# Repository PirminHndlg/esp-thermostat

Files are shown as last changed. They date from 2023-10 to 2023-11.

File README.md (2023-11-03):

# ESP-Thermostat

In Zeiten, in denen das Heizen ein Vermögen kostet, haben viele Haushalte sich entschieden, Smarte Thermostate zur Steuerung der Raumtemperatur zu kaufen. Diese kosten allerdings gerne 60-100 €, was ich für zu teuer halte und nicht bereit bin zu zahlen.

Deshalb habe ich mich dazu entschlossen, mein eigenes Thermostat zu bauen!

Das Ergebnis des Bauprozesses möchte ich hier veröffentlichen. Die Kosten für den Eigenbau sind ca. 10-15 €.

## Konzeptidee
Meine Idee ist, dass ich, wie bei gekauften smarten Thermostaten, das bestehende Thermostat ersetze. Allerdings nutze ich den Metall-Anschluss-Ring des originalen Thermostats zur Befestigung. Mit einem kleinen Schrittmotor und einem Wemos D1 Mini Mikrocontroller lässt sich der Bolzen der Heizung steuern, der beeinflusst, wie viel warmes Wasser in den Heizkörper fließt. Die Bewegung wird mit einer Schraube getätigt, die vom Motor gedreht wird und somit zur Heizung bzw von ihr weg bewegt wird.

YouTube-Video zum Bauprozess [hier](https://www.youtube.com/watch?v=YOUTUBE_VIDEO_ID_HERE) - Link fehlt noch

IMAGE ALT TEXT HERE (https://www.youtube.com/watch?v=YOUTUBE_VIDEO_ID_HERE)

### Vorteile
- OpenSource
- einfach umsetzbar
- Raumtemperatur über Zeitplan steuerbar
- billig
- 3D Drucker nicht zwingend notwenig

### Nachteile
- Thermostat braucht Stromversorgung über Kabel (Akku nicht gut möglich)
- Raumtemperatur nicht am Thermostat steuerbar sondern nur über Website / Einbindung in SmartHome-App

## Einstellungen auf lokaler Website
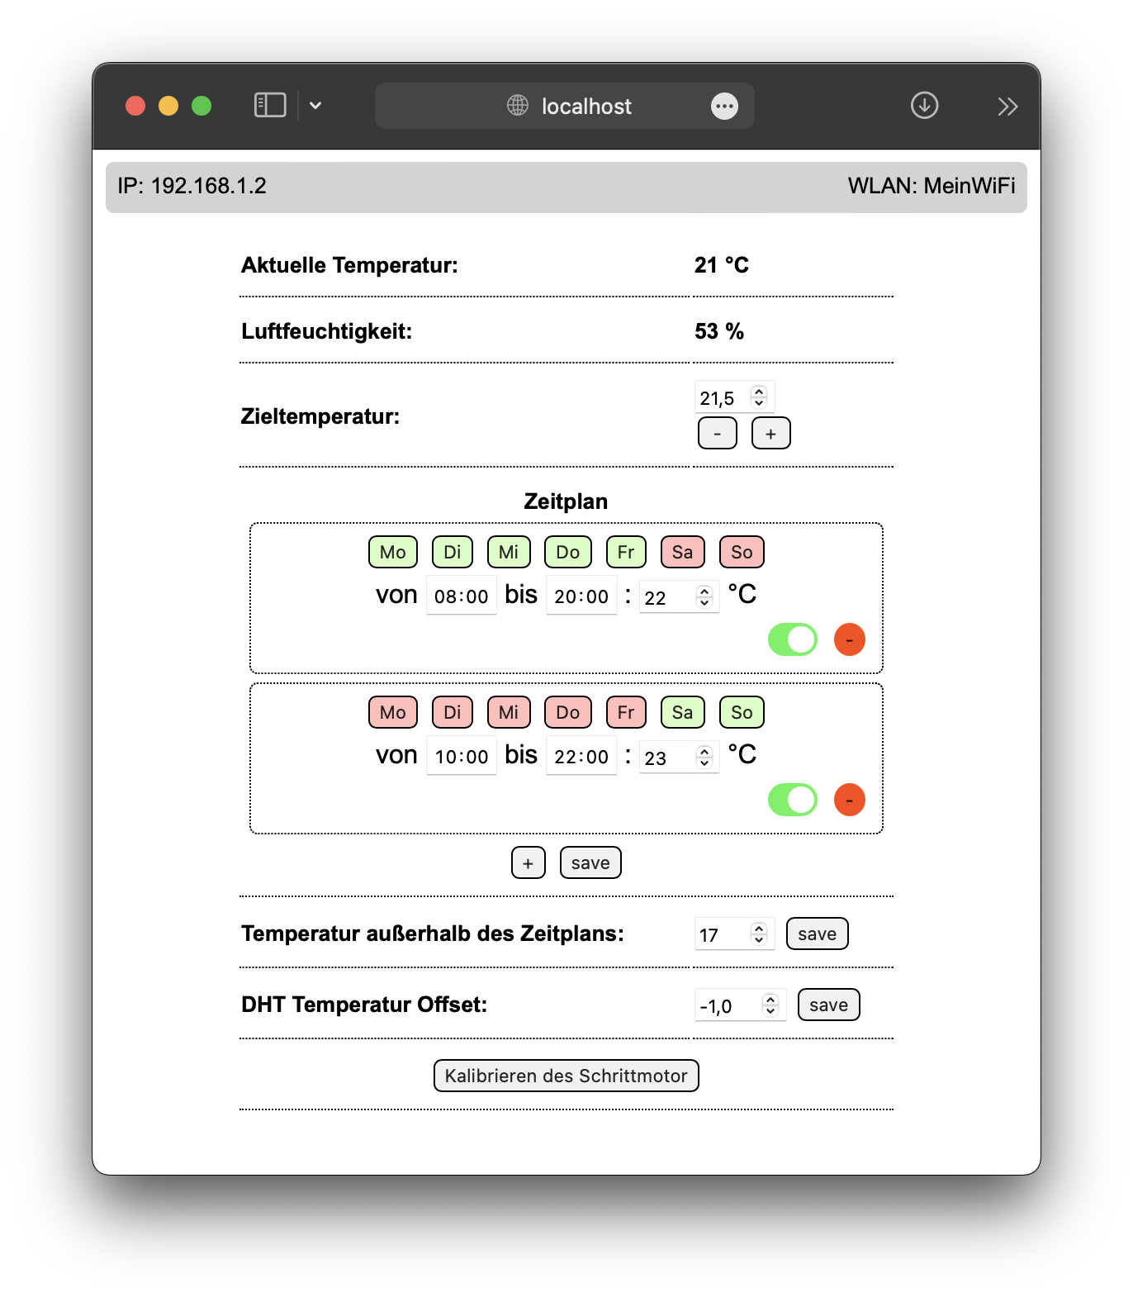
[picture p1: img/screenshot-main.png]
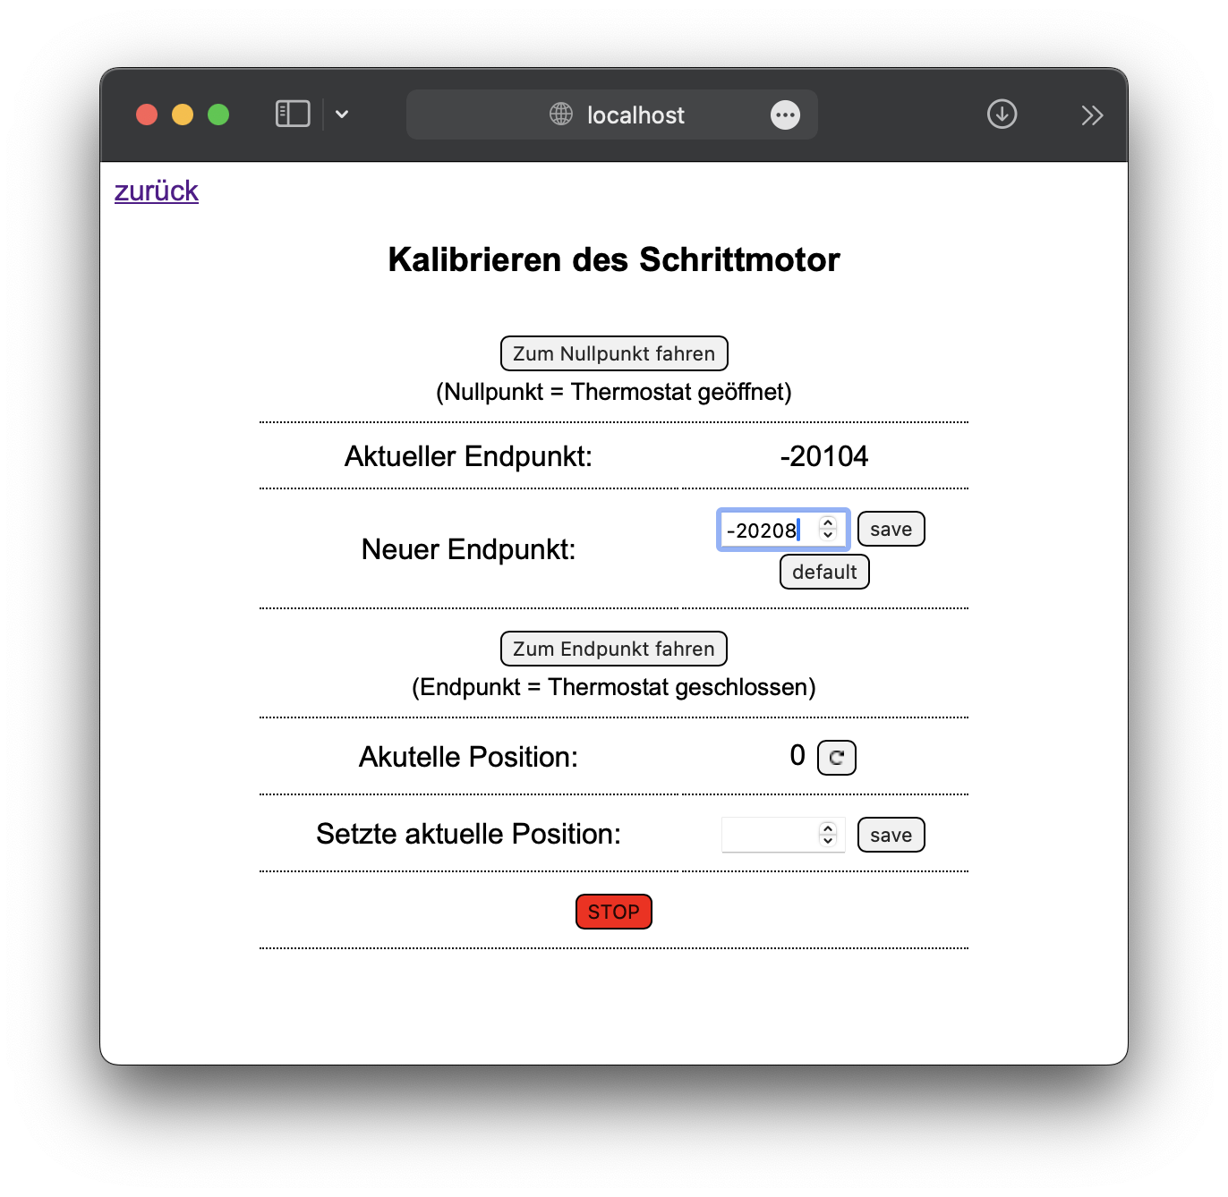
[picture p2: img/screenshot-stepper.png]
 
Der ESP erzeugt eine Website, über die sich Einstellungen für das Thermostat vornehmen lassen. Es ist möglich, einen Zeitplan zu erstellen oder die Zieltemperatur für den Raum einzustellen. Die Offsettemperatur des Temperatursensors ist dafür da, da es sein kann, dass die Temperatur direkt neben der Heizung höher ist als im restlichen Raum.

## Empfohlenes Vorwissen
- Löten
- Erfahrung mit Arduinos oder ESPs

## Benötigte Materialien
### Bauteileliste
- Wemos D1 Mini [^1]
- 28byj-48 Stepper Motor + Driver Modul (Standardmotor in Arduino Kits)
- DHT11 oder DHT22 (geht aber auch ohne)

[^1]: oder ähnlichen ESP8266, dann muss man das Case aber ggf. anpassen

### Werkzeuge
- Lötkolben
- Möglichst 3D Drucker (nicht zwingend notwendig, Kauf der Teile auch möglich)

### Kleinzeug
- 1x Female-Steckpins für D1 Mini
- Kabel zum Verlöten
- 3x M3 Schraube (25mm oder besser 30mm) + 3x M3 Mutter
- Micro USB Kabel + Netzteil

Natürlich benötigt man auch einen Laptop mit der [Arduino IDE](https://www.arduino.cc/en/software) zum Programmieren des ESPs

## 3D-Druck-Dateien
Da viele Leute keien 3D Drucker besitzen habe ich mich entschieden die gedruckten Teile selber auf [etsy](etsy.com) zu verkaufen. Dabei biete ich die Teile für den Filamentpreis an und habe kein Interesse daran große Gewinne zu machen.

Allerdings besitze ich nur einen Prusa Mini, somit ist die Qualität der Drucke nicht die beste.

Link zum Verkauf: [hier](etsy.com) - Link fehlt noch

## Richtiger Anschluss und Gewinde des Heizkörperventils ermitteln
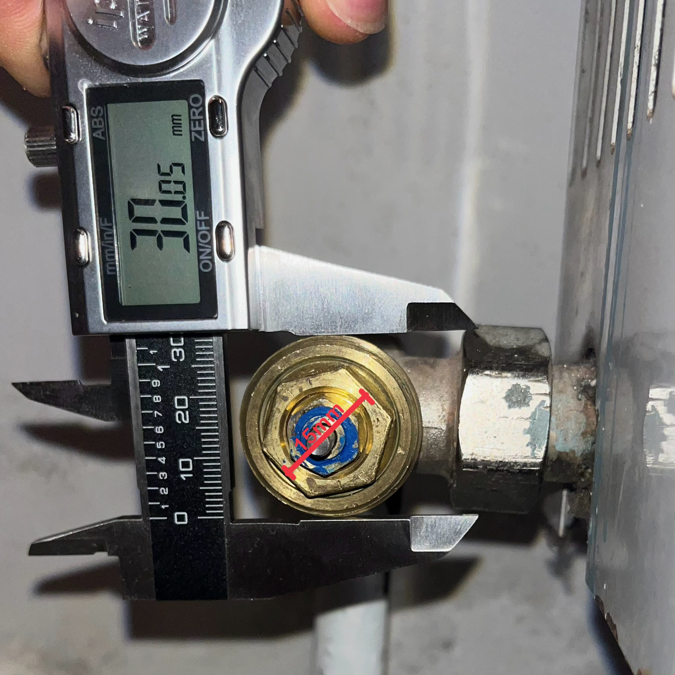
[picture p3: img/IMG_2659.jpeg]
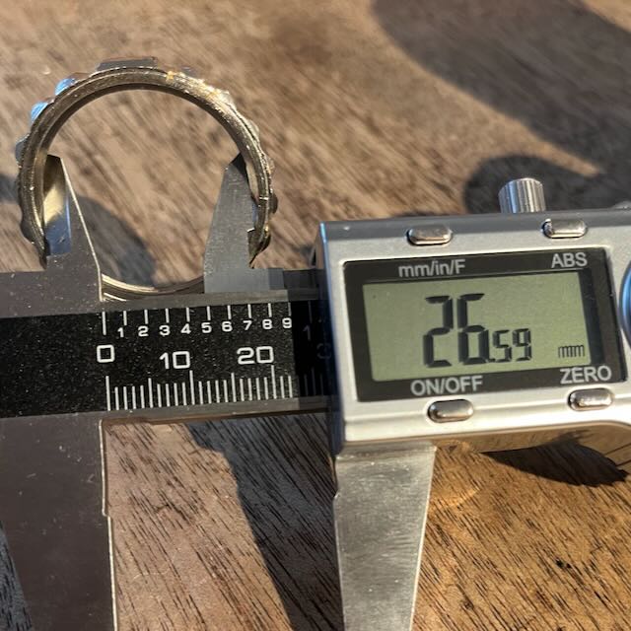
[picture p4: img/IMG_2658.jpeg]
 
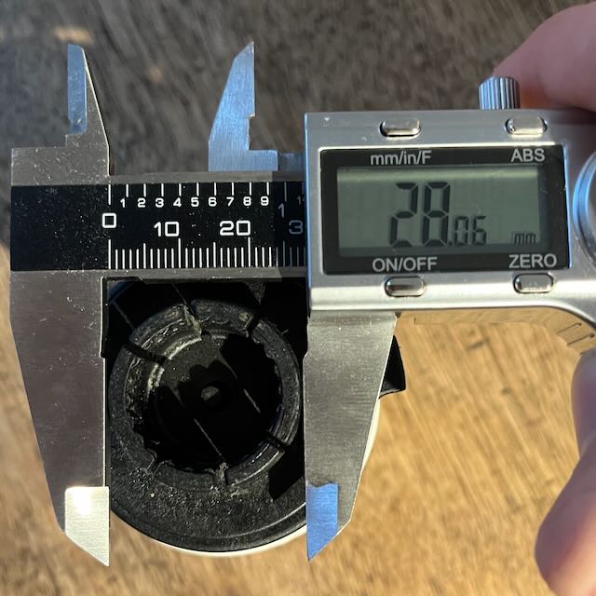
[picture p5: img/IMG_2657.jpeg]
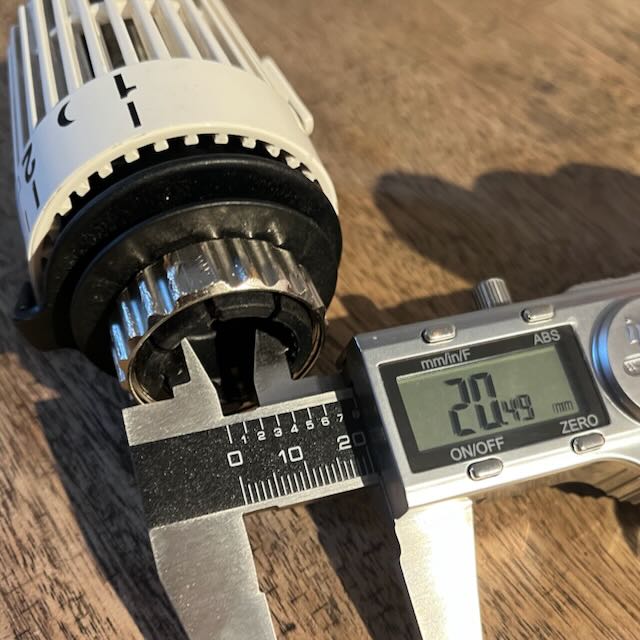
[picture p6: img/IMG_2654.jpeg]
 

#### Abmaße
- Außendurchmesser Heizungsrohr: 30mm
- Außendurchmesser Sechskant am Heizungsrohr: 15mm
- Innendurchmesser Schraubring: 26,5mm (+/- 0,5mm)
- Außendurchmesser Thermostatring: 28mm
- Innendurchmesser Thermostatring: 20,5mm

Das sind die Maße von der Heizung, für die ich mein Thermostat gebaut habe. Ich weiß nicht, ob die Thermostat-Befestigungen genormt sind. Falls es bei dir die gleichen sind, sollten die 3D-Teile passen.

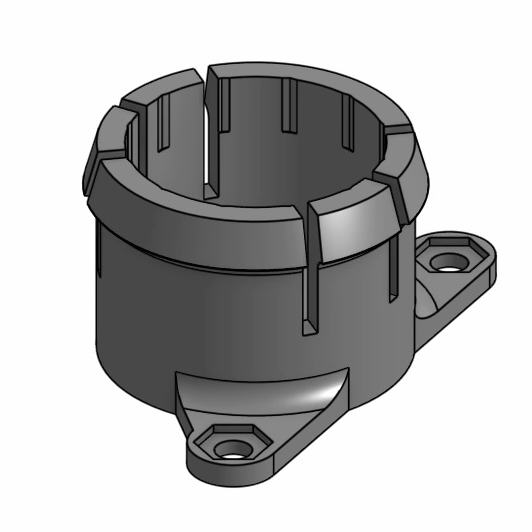
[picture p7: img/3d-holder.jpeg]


## Zusammenbau
Genaue Anweisung zum Zusammenbau im YouTube-Video [hier](youtube.com) - Link fehlt noch

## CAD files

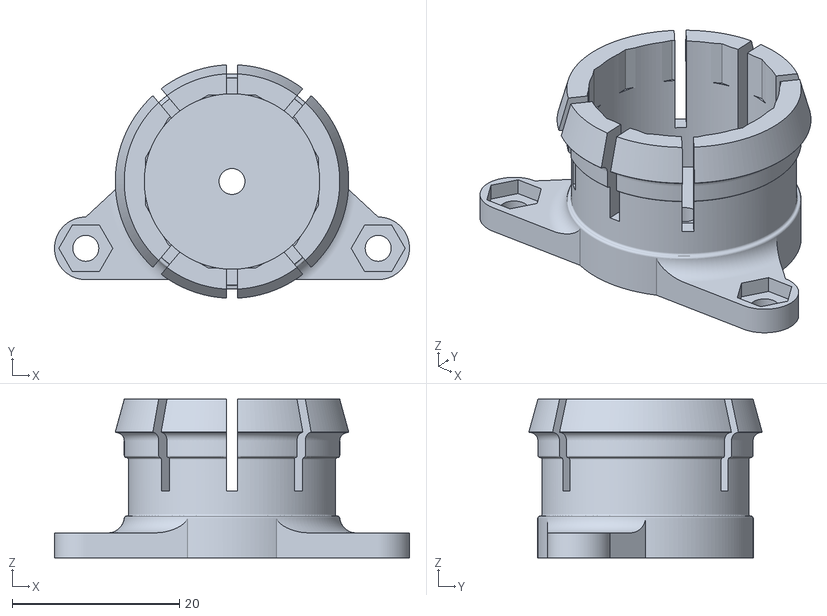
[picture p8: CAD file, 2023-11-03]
3d-files/holder_3.stl
42.5 x 27.9 x 19.0

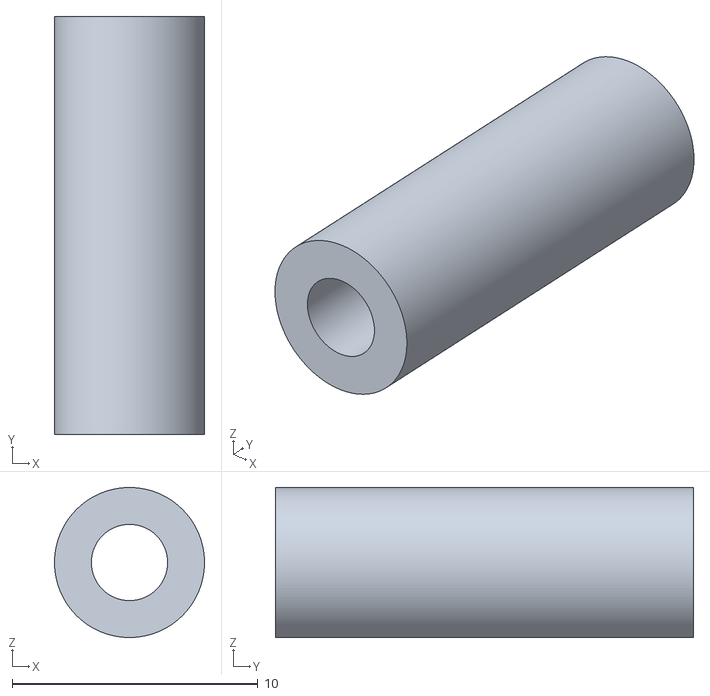
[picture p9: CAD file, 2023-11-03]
3d-files/spacer_3.stl
6.10 x 17.0 x 6.10

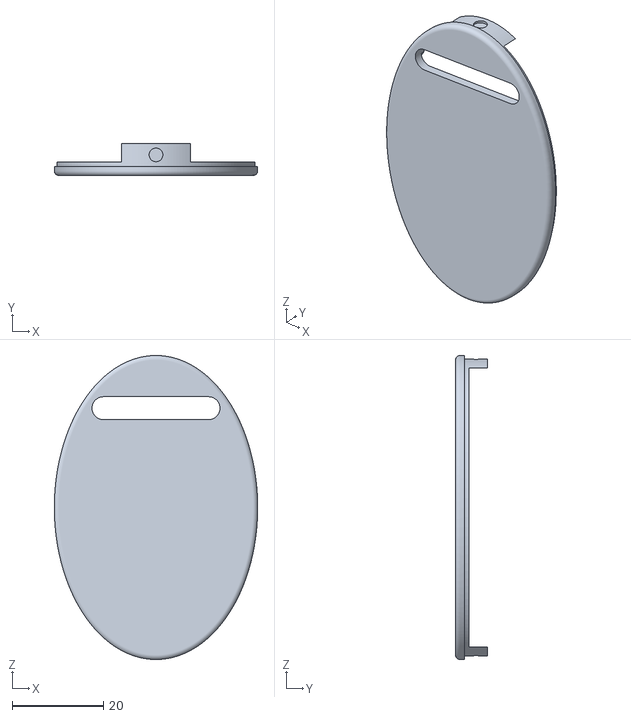
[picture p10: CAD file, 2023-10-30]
3d-files/lid_4.stl
44.5 x 7.00 x 66.5

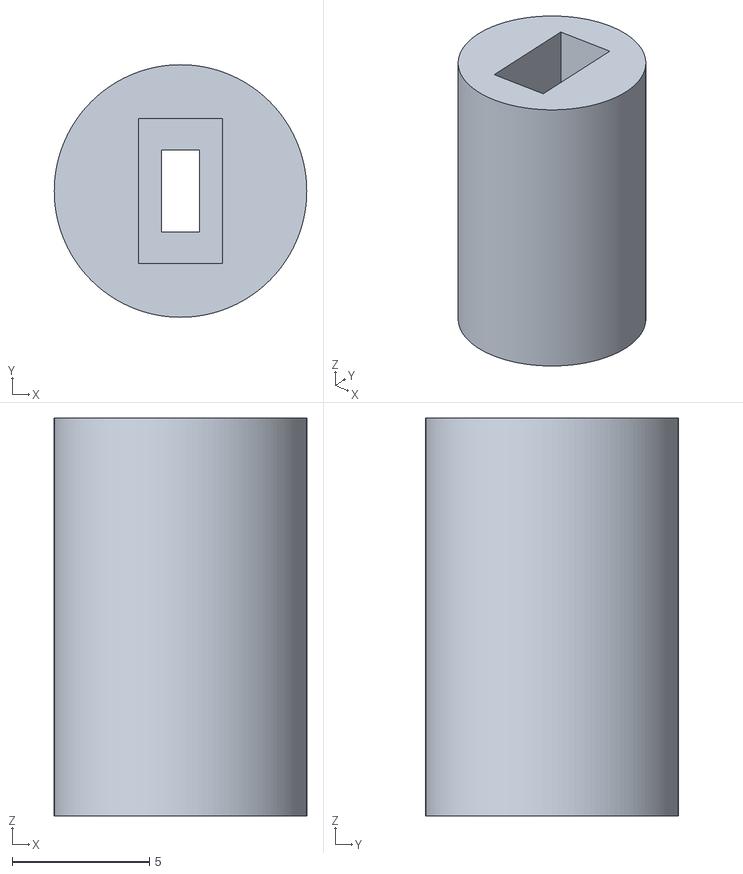
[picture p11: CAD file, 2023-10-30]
3d-files/mount-1.stl
9.20 x 9.20 x 14.5

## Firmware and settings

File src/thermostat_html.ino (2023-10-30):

#include <ESP8266WiFi.h>
#include <WiFiClient.h>
#include <ESP8266WebServer.h>
#include <Arduino.h>
#include <DHT.h>
#include <AccelStepper.h>
#include <ArduinoJson.h>
#include <FS.h>
#include <NTPClient.h>
#include <WiFiUdp.h>

#include "index.h"
#include "calibrate.h"
#include "wifi.h"
#include "extensions.h"

#define motorPin1 D8
#define motorPin2 D7
#define motorPin3 D6
#define motorPin4 D5
#define DHTPIN D2
#define DHTTYPE DHT11
#define checkInterval 50000

#define fileTimeplan "/timeplan.json"
#define fileNormtemp "/normtemp.txt"
#define fileTempOffset "/tempoffset.txt"
#define fileStepperEnd "/stepperend.txt"
#define fileCurrentStepperPos "/stepperpos.txt"

#define HALFSTEP 8
#define utcOffsetInSeconds 7200
#define defaultClose -20024

DHT dht(DHTPIN, DHTTYPE);
ESP8266WebServer server(80);
AccelStepper stepper(HALFSTEP, motorPin1, motorPin3, motorPin2, motorPin4);


WiFiUDP ntpUDP;
NTPClient timeClient(ntpUDP, "pool.ntp.org", utcOffsetInSeconds);

DynamicJsonDocument doc(1024);

int close = defaultClose;

float temp = 18;
float tempOffset = 0.0;
unsigned long lastCheck = -checkInterval;

void handleRoot() {
  String s = index_html;
  server.send(200, "text/html", s);
}

void handle_NotFound() {
  server.send(404, "text/plain", "Not found");
}

void handeCalibrate() {
  String s = calibrate_html;
  server.send(200, "text/html", s);
}

void handleGet() {
  String key = server.argName(0);
  String value = String(server.arg(0));

  Serial.print("get: " + key + " - " + value + ": ");

  if (key == "value") {
    String s = "";
    if (value == "ipadress") {
      const IPAddress& ipAddress = WiFi.localIP();
      s = String(ipAddress[0]) + String(".") + String(ipAddress[1]) + String(".") + String(ipAddress[2]) + String(".") + String(ipAddress[3]);
    } else if (value == "wifi") {
      s = String(ssid);
    } else if (value == "currenttemp") {
      s = String(dht.readTemperature() + tempOffset, 1) + "°C";
    } else if (value == "humidity") {
      s = String(int(dht.readHumidity())) + "%";
    } else if (value == "estimatedtemp") {
      s = String(temp, 1);
    } else if (value == "timeplan") {
      serializeJson(doc, s);
      Serial.println(s);
    } else if (value == "normaltemp") {
      File file = SPIFFS.open(fileNormtemp, "r");
      s = String(file.readStringUntil('\r').toFloat(), 1);
      file.close();
    } else if (value == "tempoffset") {
      s = String(tempOffset, 1);
    } else if (value == "pos") {
      s = String(stepper.currentPosition());
    } else if (value == "endpos") {
      s = String(close);
    }

    Serial.println(s);
    server.send(200, "text/plain", s);
  } else {
    server.send(404, "text/plain", "error");
  }
}

void handleSet() {

  if (server.args() == 0) {
    server.send(404, "text/plain", "error");
  }

  String s = "success";
  String key = server.argName(0);
  String value = server.arg(0);
  Serial.println("set: " + key + " - " + value);

  if (key == "temp") {
    temp = value.toInt();
    lastCheck = -checkInterval;
    if (stepper.distanceToGo() != 0) {
      stepper.moveTo(stepper.currentPosition());
    }
  } else if (key == "normaltemp") {
    File file = SPIFFS.open(fileNormtemp, "w");
    file.println(String(value));
    file.close();
  } else if (key == "pos") {
    if (value == "end") {
      stepper.moveTo(close);
    } else {
      stepper.moveTo(value.toInt());
    }
  } else if (key == "tempoffset") {
    tempOffset = value.toFloat();
    File file = SPIFFS.open(fileTempOffset, "w");
    file.println(String(value));
    file.close();
  } else if (key == "newend") {
    close = value.toInt();
    File file = SPIFFS.open(fileStepperEnd, "w");
    file.println(String(close));
    file.close();
  } else if (key == "defaultend") {
    close = defaultClose;
    File file = SPIFFS.open(fileStepperEnd, "w");
    file.println(String(close));
    file.close();
    s = defaultClose;
  } else if (key == "newpos") {
    stepper.setCurrentPosition(value.toInt());
  } else if (key == "stepper") {
    if (value == "stop") {
      stepper.moveTo(stepper.currentPosition());
      File file = SPIFFS.open(fileCurrentStepperPos, "w");
      file.println(String(stepper.currentPosition()));
      file.close();
    }
  } else {
    server.send(404, "text/plain", "error");
  }
  server.send(200, "text/plain", s);
}

void handleTimeplan() {
  if (server.argName(0) == "action" && server.arg(0) == "new") {
    doc.clear();
    Serial.println("clear");
    serializeJson(doc, Serial);
    Serial.println();
  } else if (server.args() > 1) {
    StaticJsonDocument<256> newdoc;
    newdoc["activ"] = toBoolean(server.arg("activ"));
    newdoc["start"] = server.arg("start");
    newdoc["end"] = server.arg("end");
    newdoc["temp"] = server.arg("temp");
    newdoc["days"] = serialized(server.arg("days"));

    doc[server.arg("n")] = newdoc;
    serializeJson(newdoc, Serial);
    Serial.println();
    serializeJson(doc, Serial);
    Serial.println();
  }

  File file = SPIFFS.open(fileTimeplan, "w");
  serializeJson(doc, file);
  file.close();

  file = SPIFFS.open(fileTimeplan, "r");
  deserializeJson(doc, file.readString());
  file.close();

  server.send(200, "text/plain", "success");
}

void setupServer() {
  server.on("/", handleRoot);
  server.on("/get", handleGet);
  server.on("/set", handleSet);
  server.on("/timeplan", handleTimeplan);
  server.on("/calibrate", handeCalibrate);
  server.onNotFound(handle_NotFound);

  server.begin();  //Start server
  Serial.println("HTTP server started");
}

bool wifiLogin() {
  WiFi.mode(WIFI_STA);
  Serial.printf("Connecting to %s ", ssid);
  WiFi.begin(ssid, password);

  WiFi.setAutoReconnect(true);
  WiFi.persistent(true);

  unsigned long t = millis();

  while (WiFi.status() != WL_CONNECTED) {
    delay(500);
    Serial.print(".");
    if (t > 60000) {
      return false;
    }
  }
  Serial.println(" connected");
  Serial.print("local IP:");
  Serial.println(WiFi.localIP());

  return true;
}

void setup() {
  Serial.begin(115200);

  delay(200);

  stepper.setMaxSpeed(400);
  stepper.setAcceleration(200.0);
  stepper.setSpeed(100);

  pinMode(DHTPIN, INPUT);
  dht.begin();

  Serial.println("Mounting FS...");
  if (SPIFFS.begin()) {

    if (SPIFFS.exists(fileTimeplan)) {

      File file = SPIFFS.open(fileTimeplan, "r");
      delay(10);
      String file_content = file.readString();

      auto error = deserializeJson(doc, file_content);
      if (error) {
        Serial.print(F("deserializeJson() failed with code "));
        Serial.println(error.c_str());
        File file = SPIFFS.open(fileTimeplan, "a+");
        serializeJson(doc, file);
        file.close();
        serializeJson(doc, Serial);
      }
      serializeJson(doc, Serial);
      file.close();
    } else {
      File file = SPIFFS.open(fileTimeplan, "a+");
      serializeJson(doc, file);
      file.close();
      Serial.printf("New %s File Created...\n", fileTimeplan);
    }
  }

  if (SPIFFS.exists(fileNormtemp)) {
    File file = SPIFFS.open(fileNormtemp, "r");
    temp = file.readStringUntil('\r').toFloat();
    file.close();
  } else {
    File file = SPIFFS.open(fileNormtemp, "a+");
    file.println(temp);
    Serial.printf("New %s File Created...\n", fileNormtemp);
    file.close();
  }

  if (SPIFFS.exists(fileStepperEnd)) {
    File file = SPIFFS.open(fileStepperEnd, "r");
    close = file.readStringUntil('\r').toInt();
    file.close();
  } else {
    File file = SPIFFS.open(fileStepperEnd, "a+");
    file.println(close);
    Serial.printf("New %s File Created...\n", fileStepperEnd);
    file.close();
  }

  if (SPIFFS.exists(fileTempOffset)) {
    File file = SPIFFS.open(fileTempOffset, "r");
    tempOffset = file.readStringUntil('\r').toFloat();
    file.close();
  } else {
    File file = SPIFFS.open(fileTempOffset, "a+");
    file.println(0);
    Serial.printf("New %s File Created...\n", fileTempOffset);
    file.close();
  }

  if (SPIFFS.exists(fileCurrentStepperPos)) {
    File file = SPIFFS.open(fileCurrentStepperPos, "r");
    stepper.setCurrentPosition(file.readStringUntil('\r').toInt());
    file.close();
  } else {
    File file = SPIFFS.open(fileCurrentStepperPos, "a+");
    file.println(0);
    Serial.printf("New %s File Created...\n", fileCurrentStepperPos);
    file.close();
  }

  if (wifiLogin())
    setupServer();
}


void loop() {
  server.handleClient();

  if (millis() - lastCheck > checkInterval && stepper.distanceToGo() == 0) {
    //für aktuelle zeit nach temp checken
    timeClient.update();

    int j = 0;
    while (true) {
      if (!doc.containsKey(String(j)) || j > 99)
        break;

      Serial.println("____");

      serializeJson(doc, Serial);
      Serial.println();

      StaticJsonDocument<512> newdoc = doc[String(j)];

      if (!toBoolean(newdoc["activ"])) {
        continue;
      }

      serializeJson(newdoc, Serial);
      Serial.println();

      serializeJson(newdoc["days"], Serial);
      Serial.println();

      JsonArray days = newdoc["days"].as<JsonArray>();

      for (JsonVariant v : days) {
        int day = v.as<int>();
        Serial.println(day);
        Serial.println(timeClient.getDay());

        if (day == timeClient.getDay()) {

          Serial.println("right day");
          serializeJson(newdoc["start"], Serial);
          Serial.println();

          if (newdoc["start"] == (String(timeClient.getHours()) + ":" + String(timeClient.getMinutes()))) {
            temp = float(newdoc["temp"]);
            Serial.println("new temp");
            Serial.println(temp);
            break;
          } else if (newdoc["end"] == (String(timeClient.getHours()) + ":" + String(timeClient.getMinutes()))) {
            File file = SPIFFS.open(fileNormtemp, "r");
            temp = file.readStringUntil('\r').toFloat();
            file.close();

            Serial.println("normtemp");
            Serial.println(temp);
            break;
          }

          continue;
        }
      }

      j++;
    }

    float currentTemp = dht.readTemperature() + tempOffset;
    Serial.print("currentTemp: ");
    Serial.println(currentTemp, 1);
    Serial.print("temp: ");
    Serial.println(temp);

    if (temp - currentTemp > 0.5) {  // zu kalt
      if (stepper.currentPosition() != 0) {
        Serial.println("Thermostat öffnen");
        stepper.moveTo(0);
      }
    } else if (currentTemp - temp > 2.5) {  //zu warm
      if (stepper.currentPosition() != close) {
        Serial.println("Thermostat schliessen");
        stepper.moveTo(close);
      }
    } else if (currentTemp - temp > 0.5) {
      if (stepper.currentPosition() != close / 2) {
        Serial.println("Thermostat halb öffnen");
        stepper.moveTo(close / 2);
      }
    }

    lastCheck = millis();
  }

  if (stepper.distanceToGo() != 0) {
    stepper.run();
    if (stepper.distanceToGo() == 0) {
      stepper.run();
      File file = SPIFFS.open(fileCurrentStepperPos, "w");
      file.println(String(stepper.currentPosition()));
      file.close();
    }
  }
}

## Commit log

2023-10-30 added a html button for default
2023-10-30 adding a response to the default stepper end pos
2023-10-30 stop stepper should save current pos to SPIFFS
2023-10-30 stl files added
    [holder_2 (1).stl, lid_4.stl, mount-1.stl]
